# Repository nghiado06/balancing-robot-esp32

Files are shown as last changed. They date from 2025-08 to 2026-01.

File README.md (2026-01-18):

# SELF BALANCING ROBOT
This project involves building a self-balancing robot using an Esp32 microcontroller. The robot uses sensors to detect its orientation and adjusts its motors to maintain balance.

## Components Used
- Esp32 Microcontroller
- MPU6050 Gyroscope and Accelerometer
- A4988 Motor Driver
- Stepper Motors NEMA 17
- Power Supply (Battery) 12V 2A
- PCB Board

## Features
- Real-time balancing using sensor data
- Motor control for movement and balance
- Compact and efficient design
- Easy to assemble and program

## Installation
1. Clone the repository to your local machine.
   ```
   git clone
    ```
2. Install the required libraries for the Esp32 and MPU6050.
3. Connect the components as per the wiring diagram provided in the repository.
4. Upload the code to the Esp32 using Arduino IDE or any compatible platform.\
5. Power on the robot and test its balancing capabilities.
6. Adjust the PID parameters in the code for optimal performance.

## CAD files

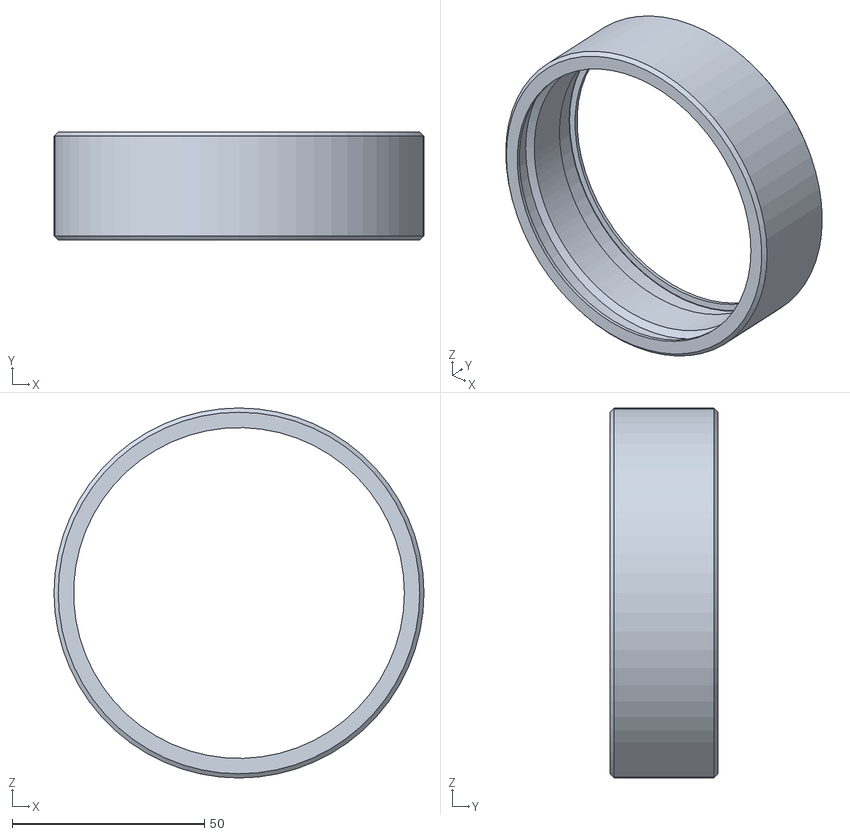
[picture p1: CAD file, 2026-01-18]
balancing-robot-mechanical/tyre.STL
96.2 x 28.2 x 96.2

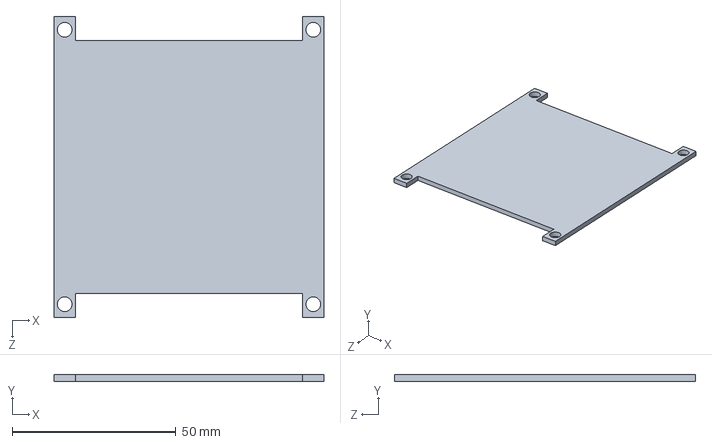
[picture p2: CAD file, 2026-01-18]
balancing-robot-mechanical/body.SLDPRT
82.5 x 2.00 x 92.0 mm

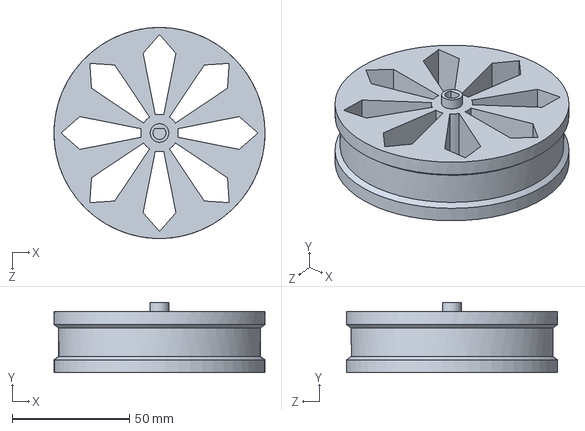
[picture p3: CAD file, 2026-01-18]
balancing-robot-mechanical/wheel.SLDPRT
90.0 x 30.0 x 90.0 mm

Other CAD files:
balancing-robot-mechanical/battey plane.SLDPRT
balancing-robot-mechanical/tyre.gcode.3mf
balancing-robot-mechanical/battey plane.STL
balancing-robot-mechanical/body.3mf
balancing-robot-mechanical/body.STL
balancing-robot-mechanical/wheel.STL

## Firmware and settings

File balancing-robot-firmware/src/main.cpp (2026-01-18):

#include <Arduino.h>
#include "config.h"
#include "imu_process.h"
#include "stepper_control.h"
#include "data_handling.h"
#include "tuning.h"

ImuProcess imu;
StepperControl stepper;
DataHandling dataHandler;
ControlUI ui;

// Timing
uint32_t lastUs = 0;
uint32_t startMs = 0;

// PID parameters
float kp = 31.0f;
float ki = 0.02f;
float kd = 1.2f;

// Imu data
float pitch = 0.0f;
float gyroY = 0.0f;
bool needCalibrate = true;

void offBuzzer();

void setup()
{
  Serial.begin(115200);
  delay(300); // Allow time for Serial to initialize
  Serial.println("Balancing Robot Firmware Starting...");

  imu.begin();
  stepper.begin();

  // Initialize timing
  startMs = millis();
  lastUs = micros();

  // Buzzer indication
  pinMode(BUZZER_PIN, OUTPUT);
  offBuzzer();

  // Remote UI
  ui.begin();

  ui.setName(1, "Kp+");
  ui.setName(2, "Kp-");
  ui.setName(3, "Kd+");
  ui.setName(4, "Kd-");
  ui.setName(5, "Ki+");
  ui.setName(6, "Ki-");
}

void loop()
{
  // ui.remoteProcess();
  // Timing
  uint32_t nowUs = micros();
  uint32_t nowMs = millis();
  if (nowUs - lastUs < LOOP_US)
    return;

  float dt_us = (nowUs - lastUs);
  float dt = (nowUs - lastUs) * 1e-6f;
  lastUs = nowUs;

  // IMU Processing
  imu.process(pitch, gyroY, dt_us, needCalibrate);
  if (fabsf(pitch) > FALL_ANGLE_DEG)
  {
    stepper.stopAll();
    dataHandler.resetPID();
    return;
  }

  // Pid Control
  float omegaCmd = 0.0f;
  dataHandler.pidCompute(pitch, gyroY, dt, omegaCmd);

  // Debug Output
  static uint32_t lastPrintMs = 0;
  if (millis() - lastPrintMs >= 50)
  { // 20 Hz
    Serial.printf("Pitch=%.2f deg, GyroY=%.2f dps, Omega=%.2f deg/s\n",
                  pitch, gyroY, omegaCmd);
    lastPrintMs = millis();
  }

  // Set Motor Speeds
  stepper.setOmegaDegS(omegaCmd, omegaCmd);

  // // Tuning
  // if (ui.isFunction1Pressed())
  // {
  //   kp += 1.0f;
  // }
  // if (ui.isFunction2Pressed())
  // {
  //   kp -= 1.0f;
  // }
  // if (ui.isFunction3Pressed())
  // {
  //   kd += 0.1f;
  // }
  // if (ui.isFunction4Pressed())
  // {
  //   kd -= 0.1f;
  // }
  // if (ui.isFunction5Pressed())
  // {
  //   ki += 0.01f;
  // }
  // if (ui.isFunction6Pressed())
  // {
  //   ki -= 0.01f;
  // }
  // dataHandler.setPIDParams(kp, ki, kd);
  // ui.addLog("Kp: " + String(kp, 2), 0);
  // ui.addLog("Kd: " + String(kd, 2), 1);
  // ui.addLog("Ki: " + String(ki, 3), 2);
}

void offBuzzer()
{
  digitalWrite(BUZZER_PIN, LOW);
}

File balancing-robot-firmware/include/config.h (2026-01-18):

#ifndef CONFIG_H
#define CONFIG_H

#include <cmath>
#include <Arduino.h>

// Loop Config
constexpr float LOOP_HZ = 200.0f;                        // loop frequency in Hz
constexpr uint32_t LOOP_US = (uint32_t)(1e6f / LOOP_HZ); // loop period in microseconds

// Imu Config
constexpr uint32_t CALIB_MS = 2000; // calib time in milliseconds
constexpr float ALPHA = 0.98f;      // Complementary filter coefficient

// Motor Config
constexpr uint32_t FULL_STEPS_PER_REV = 200;                       // 1.8deg
constexpr uint32_t MICROSTEP = 16;                                 // e.g., 1/16
constexpr uint32_t STEPS_PER_REV = FULL_STEPS_PER_REV * MICROSTEP; // 3200

constexpr bool INVERT_DIR_L = true;
constexpr bool INVERT_DIR_R = false;

constexpr int LEDC_CH_L = 0;
constexpr int LEDC_CH_R = 1;
constexpr int LEDC_RES_BITS = 10;                            // 0..1023
constexpr uint32_t LEDC_DUTY_50 = 1U << (LEDC_RES_BITS - 1); // ~50%

constexpr float STEP_HZ_MIN_RUN = 1.0f; // <1Hz consider as stop
constexpr float STEP_HZ_MAX = 20000.0f; // you can increase if

constexpr float OMEGA_DEADBAND_DEG_S = 1.5f; // deg/s
constexpr float FALL_ANGLE_DEG = 70.0f;      // angle to consider as fall

#endif // CONFIG_H

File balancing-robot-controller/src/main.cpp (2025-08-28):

#include <Arduino.h>
#include <WiFi.h>
#include <esp_now.h>
#include <Wire.h>
#include <MPU6050_tockn.h>

MPU6050 mpu(Wire);
struct HandMotionRaw
{
  uint8_t ver;
  uint32_t seq;
  uint32_t ts_ms;
  float ax, ay, az;
  float gx, gy, gz;
  uint16_t vbat_mV;
  uint8_t flags;
  uint16_t crc16;
};

uint8_t RECEIVER_MAC[6] = {0x24, 0x6F, 0x28, 0xAA, 0xBB, 0xCC};

static uint16_t crc16(const uint8_t *data, size_t n)
{
  uint16_t c = 0xFFFF;
  for (size_t i = 0; i < n; ++i)
  {
    c ^= data[i];
    for (int b = 0; b < 8; ++b)
      c = (c & 1) ? (c >> 1) ^ 0xA001 : (c >> 1);
  }
  return c;
}

static esp_now_peer_info_t peer{};
static HandMotionRaw pkt{};
static uint32_t seq = 0;

void setup()
{
  Serial.begin(115200);
  delay(100);

  Wire.begin();
  mpu.begin();
  mpu.calcGyroOffsets(true);

  WiFi.mode(WIFI_STA);
  if (esp_now_init() != ESP_OK)
  {
    Serial.println("ESP-NOW init failed!");
    while (1)
      delay(1000);
  }

  memcpy(peer.peer_addr, RECEIVER_MAC, 6);
  peer.channel = 0;
  peer.encrypt = false;
  if (esp_now_add_peer(&peer) != ESP_OK)
  {
    Serial.println("Add peer failed!");
    while (1)
      delay(1000);
  }

  Serial.println("Sender ready.");
}

void loop()
{
  static uint32_t last = 0;
  uint32_t now = millis();
  if (now - last < 10)
  {
    delay(1);
    return;
  }
  last = now;

  mpu.update();
  pkt.ver = 1;
  pkt.seq = ++seq;
  pkt.ts_ms = now;
  pkt.ax = mpu.getAccX();
  pkt.ay = mpu.getAccY();
  pkt.az = mpu.getAccZ();
  pkt.gx = mpu.getGyroX();
  pkt.gy = mpu.getGyroY();
  pkt.gz = mpu.getGyroZ();
  pkt.vbat_mV = 0;
  pkt.flags = 0;

  pkt.crc16 = 0;
  pkt.crc16 = crc16(reinterpret_cast<const uint8_t *>(&pkt), sizeof(pkt));

  esp_err_t e = esp_now_send(RECEIVER_MAC, (const uint8_t *)&pkt, sizeof(pkt));
  if (e != ESP_OK)
  {
  }
}

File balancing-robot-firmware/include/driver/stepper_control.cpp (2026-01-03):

#include "stepper_control.h"

StepperControl::StepperControl()
    : motorLeft_{STEP_L_PIN, DIR_L_PIN, INVERT_DIR_L, LEDC_CH_L, true, 0.0f},
      motorRight_{STEP_R_PIN, DIR_R_PIN, INVERT_DIR_R, LEDC_CH_R, true, 0.0f}
{
}

StepperControl::~StepperControl()
{
}

void StepperControl::begin()
{
    pinMode(motorLeft_.stepPin, OUTPUT);
    pinMode(motorLeft_.dirPin, OUTPUT);
    pinMode(motorRight_.stepPin, OUTPUT);
    pinMode(motorRight_.dirPin, OUTPUT);
    pinMode(ENABLE_PIN, OUTPUT);

    digitalWrite(motorLeft_.stepPin, LOW);
    digitalWrite(motorRight_.stepPin, LOW);

    enable(true);

    // Setup LEDC channels (initial freq is placeholder)
    ledcSetup(motorLeft_.channel, 1000, LEDC_RES_BITS);
    ledcAttachPin(motorLeft_.stepPin, motorLeft_.channel);
    ledcWrite(motorLeft_.channel, 0);

    ledcSetup(motorRight_.channel, 1000, LEDC_RES_BITS);
    ledcAttachPin(motorRight_.stepPin, motorRight_.channel);
    ledcWrite(motorRight_.channel, 0);

    // Default DIR
    setDirection(MotorSide::Left, true);
    setDirection(MotorSide::Right, true);
    motorLeft_.lastForward = true;
    motorRight_.lastForward = true;
}

void StepperControl::enable(bool enable)
{
    // A4988 normal: LOW=enable, HIGH=disable
    digitalWrite(ENABLE_PIN, enable ? LOW : HIGH);
}

void StepperControl::stop(MotorSide side)
{
    MotorLEDC &m = getMotor(side);
    ledcWrite(m.channel, 0); // duty = 0 => stop stepping
    m.lastStepHz = 0.0f;
}

void StepperControl::setDirection(MotorSide side, bool forward)
{
    MotorLEDC &m = getMotor(side);
    bool logic = m.invertDir ? !forward : forward;
    digitalWrite(m.dirPin, logic ? HIGH : LOW);
}

void StepperControl::setStepHz(MotorSide side, float f_step_hz)
{
    MotorLEDC &m = getMotor(side);

    float f_clamped = clampStepHz(f_step_hz);
    if (f_clamped < STEP_HZ_MIN_RUN)
    {
        // Consider as stop
        stop(side);
        return;
    }

    ledcChangeFrequency(m.channel, (uint32_t)f_clamped, LEDC_RES_BITS);
    ledcWrite(m.channel, LEDC_DUTY_50);

    m.lastStepHz = f_clamped;
}

void StepperControl::setOmegaDegS(MotorSide side, float omega_deg_s)
{
    MotorLEDC &m = getMotor(side);

    if (fabsf(omega_deg_s) < OMEGA_DEADBAND_DEG_S)
    {
        // Consider as stop
        stop(side);
        return;
    }

    // Deg to Rad
    float omega_rad_s = degToRad(omega_deg_s);

    bool forward = (omega_rad_s >= 0.0f);

    // If direction changed: stop PWM -> change DIR -> start again (avoid glitch)
    if (forward != m.lastForward)
    {
        stop(side);
        delayMicroseconds(5);
        setDirection(side, forward);
        m.lastForward = forward;
        delayMicroseconds(5);
    }

    float f_step = omegaToStepHz(fabsf(omega_rad_s));
    setStepHz(side, f_step);
}

void StepperControl::setOmegaDegS(float omegaL_deg_s, float omegaR_deg_s)
{
    setOmegaDegS(MotorSide::Left, omegaL_deg_s);
    setOmegaDegS(MotorSide::Right, omegaR_deg_s);
}

void StepperControl::stopAll()
{
    stop(MotorSide::Left);
    stop(MotorSide::Right);
}

float StepperControl::omegaToStepHz(float omega_rad_s)
{
    // f_step = (omega_rad_s * STEPS_PER_REV) / (2 * pi)
    return (float)((double)omega_rad_s * (double)STEPS_PER_REV) / (2.0 * M_PI);
}

float StepperControl::clampStepHz(float f)
{
    if (f < 0.0f)
        f = -f;
    if (f > STEP_HZ_MAX)
        return STEP_HZ_MAX;
    return f;
}

MotorLEDC &StepperControl::getMotor(MotorSide side)
{
    if (side == MotorSide::Left)
        return motorLeft_;
    else
        return motorRight_;
}

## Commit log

2025-08-26 Update Buzzer and Button
    [main.cpp]
2026-01-03 update main flow
    [Tính chọn Động cơ.xlsx]
